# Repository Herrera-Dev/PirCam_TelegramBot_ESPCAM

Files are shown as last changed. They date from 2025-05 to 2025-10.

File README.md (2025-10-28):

# ESP32-CAM con TelegramBot

Consiste en un sistema de monitores de seguridad basado en un **ESP32-CAM**, que interactúa con un bot de **Telegram**. El dispositivo captura fotos usando la cámara integrada y las envía a los usuarios registrados cuando detecta movimiento mediante un sensor PIR. Además, tiene múltiples funcionalidades controlables a través de Telegram, como **activar o desactivar el modo de vigilancia**, **tomar fotos bajo demanda**, **transmitir video en la red local** o **controlar el modo de ahorro de energía.**

> ⚠️ Al encenderse, la ESP32-CAM intenta cargar las configuraciones almacenadas. Si no encuentra el **token del bot**, las **credenciales Wi-Fi** o al menos **un usuario**, entra en modo configuración usando **WiFiManager** para obtener estos datos para obtenerlos.

<p align="center">
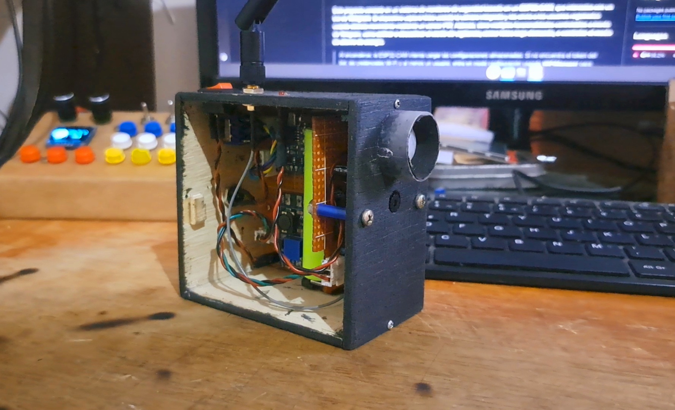
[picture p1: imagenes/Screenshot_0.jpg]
  
</p>

## 🛠️ Configuración del Entorno
### Software
- **IDE:** Arduino `v1.8.x` o `v2.3.x`
- **Framework:** Arduino ESP32 `v3.0.7`
- **Board:** `AI Thinker ESP32-CAM`
- **Partition:** `Regular 4MB with spiffs(1.2MB APP/1.5MB SPIFFS).`</b>    
  En caso de usar la función de **OTA**: `Minimal SPIFFS(1.9 APP with OTA/ 190KB SPIFFS).`

### Librerías

- **WiFiManager** `v2.0.17`: Para gestionar la conexión Wi-Fi.
- **UniversalTelegramBot** `v1.3.0`: Para la integración con el bot de Telegram.
- **ArduinoJson** `v7.4.1`: Para el manejo de JSON en la comunicación con el bot de Telegram.
- **TelnetStream** `v1.3.0`: Usar solo si no dispone de una comunicación serial.

## 🔧 Hardware

- 1x Board ESP32-CAM y antena externa (opcional).
- 1x Sensor de movimiento PIR HC-SR501.
- 1x Step-Up MT3608 DC-DC
- 1x Modulo de carga TP4056.
- 1x Portabateria 18650.
- 1x Bateria 18650.
- 1x Interruptor 6P DPDT.
- 1x Diodo led.
- Resistencias 100 kohm, 10 kohm y 100 ohm.

## 🔌 Diagrama

<p align="center">
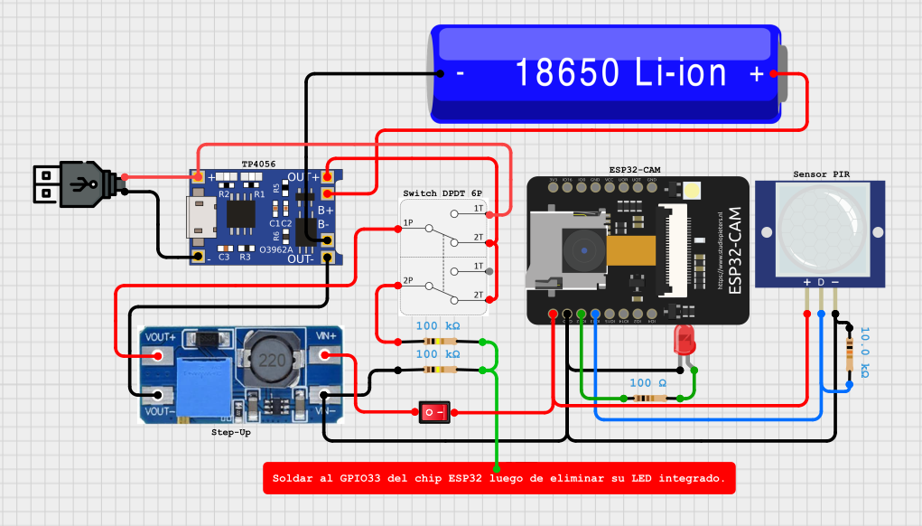
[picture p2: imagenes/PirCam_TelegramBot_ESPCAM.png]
Circuito
  
</p>

---

> ⚠️ Primero verificar que funcione bien la **PSRAM** de la la placa **ESP32-CAM** usando el modelo de placa: **AI Thinker ESP32-CAM** al parecer algunas unidades tienen ese defecto desde fabrica.

```c
#include <Arduino.h>
void setup() {
  Serial.begin(115200);
  delay(1000);

  if (psramFound()) {
    Serial.println("PSRAM está habilitada y funcionando.");
  } else {
    Serial.println("PSRAM no está habilitada o disponible.");
  }
}

void loop() {
}
```

> Si ocurren fallas como `Error al iniciar la camara`, `Error al capturar la foto` o `reinicios por culpa del WDT` recomendacion desactivar la funcion del **Watchdogs**.

## 🖼️ Capturas

<p align="center">
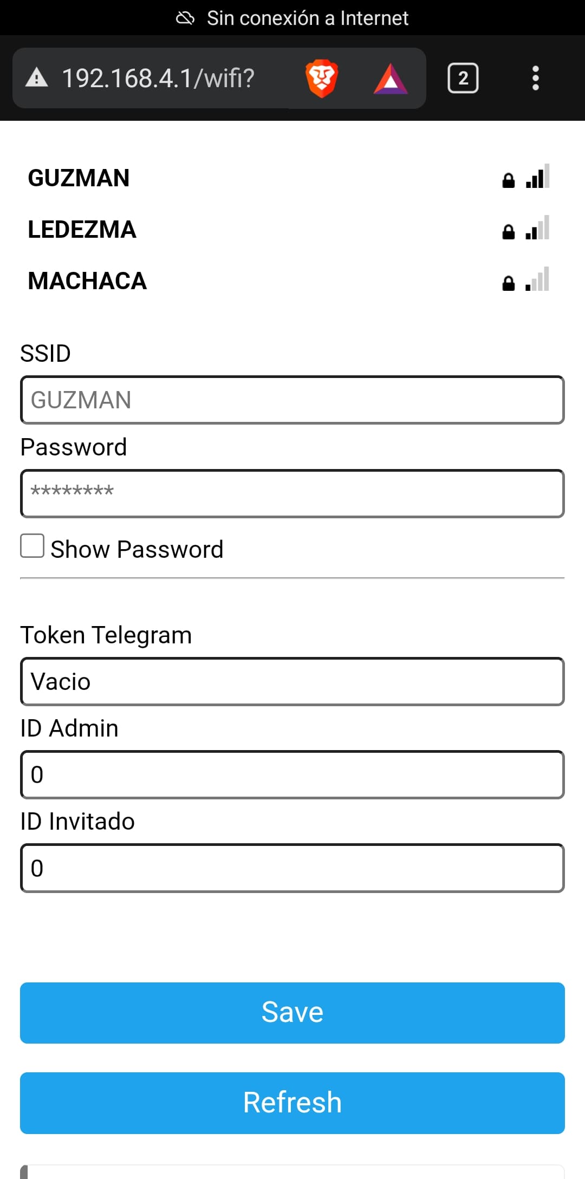
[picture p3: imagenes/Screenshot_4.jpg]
  
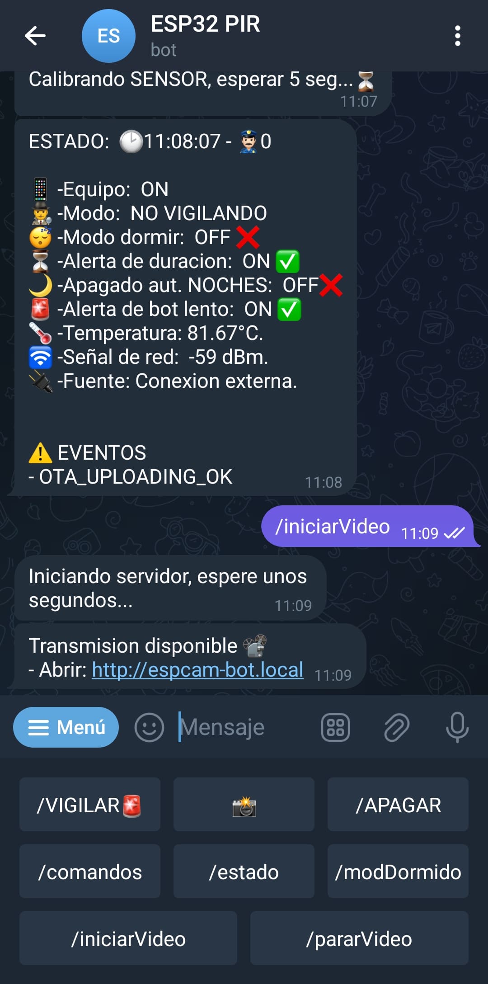
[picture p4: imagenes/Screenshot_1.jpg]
  
</p>

<p align="center">
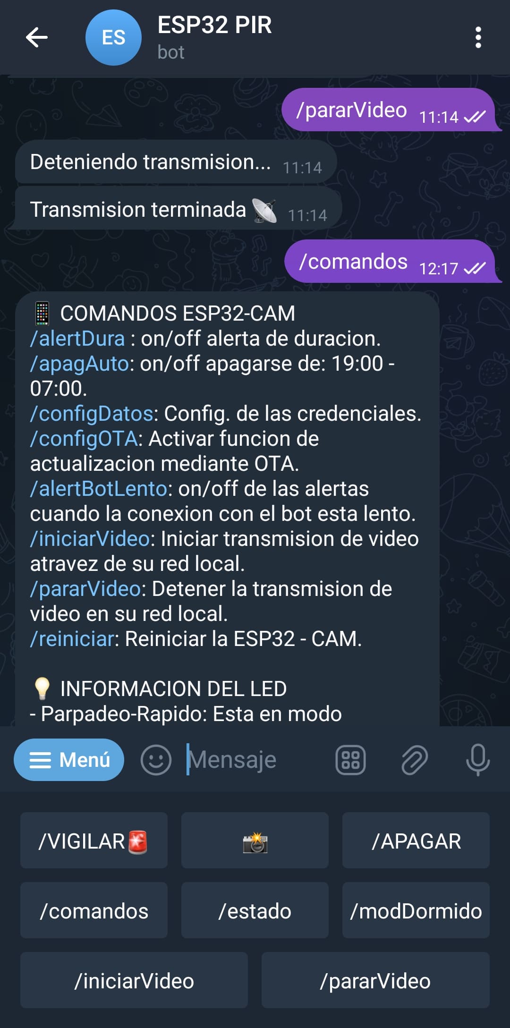
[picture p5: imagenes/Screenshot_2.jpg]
  
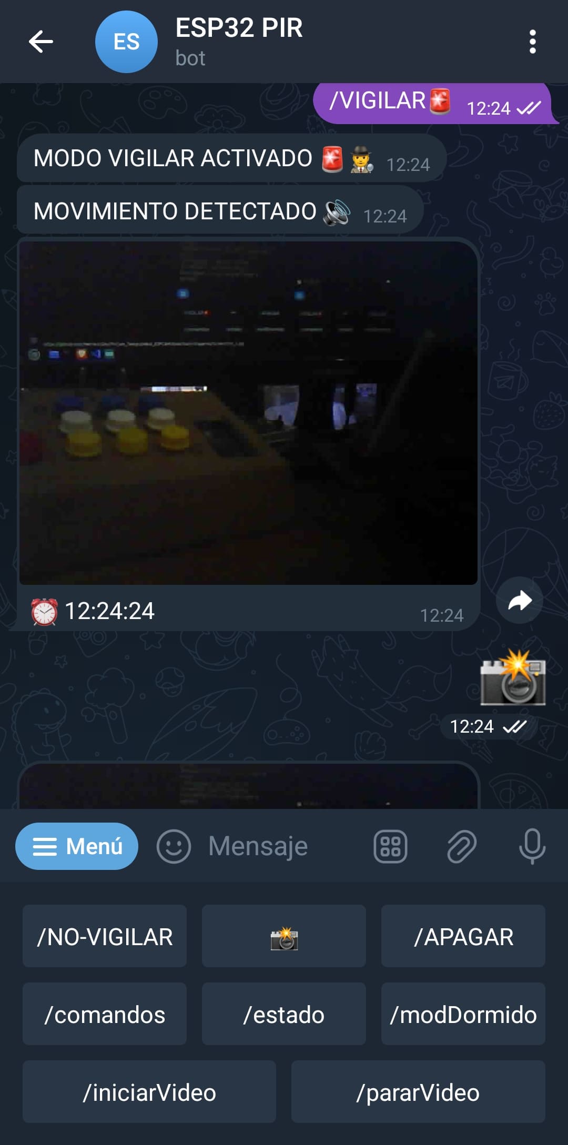
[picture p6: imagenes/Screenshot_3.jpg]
  
</p>

## 🌐 Características del Bot de Telegram

| **Comando** | **Descripción** |
|---|---|
| `/estado` | Muestra el estado del sistema: <ul><li>Hora actual y número de usuarios en vigilancia</li><li>Estado del dispositivo (ON/OFF)</li><li>Modo vigilancia (ON/OFF)</li><li>Modo ahorro de energía (ON/OFF)</li><li>Alerta de duración del movimiento (ON/OFF)</li><li>Apagado automático (ON/OFF)</li><li>Temperatura interna *(SENSOR INTERNO NO CONFIABLE)*</li><li>Intensidad de la señal WiFi</li><li>Tipo de alimentación (externa o batería)</li></ul> |
| `/VIGILAR` / `/NO-VIGILAR` | Activa o desactiva el modo vigilancia. Envía foto al detectar movimiento. |
| `/foto` | Solicita una foto en cualquier momento. |
| `/APAGAR` / `/ENCENDER` | Apaga o enciende el dispositivo. Usa *deep sleep* al apagarse. |
| `/modDormido` / `/modDespierto` | Activa o desactiva el modo ahorro de energía (deep sleep con PIR). |
| `/iniciarVideo` / `/pararVideo` | Iniciar o detener la transmisión de video a través de su red local: [http://espcam-bot.local](http://espcam-bot.local) --> [VER IMAGEN](imagenes/Screenshot_5.jpg)|
| `/comandos` | Muestra comandos adicionales y alerta LED:<ul><li>`/alertDura`: ON/OFF – LED se mantiene encendido con movimiento.</li><li>`/apagAuto`: ON/OFF – Apagado automático nocturno.</li><li>`/configOTA`: Activar OTA (solo admin).</li><li>`/configDatos`: Reinicia para reconfigurar con WiFiManager (solo admin).</li><li>`/reiniciar`: Reinicia la ESP32-CAM.</li></ul> |

  ```c
  💡 INFORMACION DEL LED
  - Parpadeo_Rapido: Esta en modo configuración o error de acceso a la memoria.
  - Parpadeo_Normal: Calibrando sensor luego de iniciar.
  - Un Parpadeo: Captura una foto.
  - Encendido: Cuando se detecta movimiento (solo si esta activado la opcion `/alertDura`).
  ```

- **Alerta de batería**: Notificar si la batería baja por debajo del 15% cuando se esta usando la batería como fuente de alimentacion.
- **Lentitud con el bot**: Cuando esta en modo-vigilar notificar si el bot tarda en verificar la existencia de nuevos mensajes y eso genera un retraso en cada interacción.
- **Sobrecalentamiento**: Notificar cuando el sensor interno de temperatura alcance un umbral definido, (**CABE ACLARAR QUE EL SENSOR INTERNO DE ESTA ESP32 NO ES CONFIABLE**) recomendación usar usar un sensor externo.
> ⚠️ Las mensajes de posible fallo se muestra en los **mensajes de bienvenida** o en el **portal de WifiManager**.

### Calidad de imagen y video
La **calidad de las imagenes** se debe cambiar desde `void configCamara()` **mayor calidad** y **tamaño de imagen** significa mayor consumo electrico y menor rendimiento de la ESP32.

```c
config.frame_size = FRAMESIZE_VGA; // FRAMESIZE_ + QVGA|CIF|VGA|SVGA|XGA|SXGA|UXGA 
config.jpeg_quality = 30;          // 0-63 un número más bajo significa mayor calidad de imagen.
```

### Funciones Dev
En caso de realizar modificaciones.

- **Actualización OTA (Over-the-Air):** **(Aunque esta funcion ya biene integrada en WifiManager)**. El proyecto incluye la funcionalidad de actualización OTA, lo que permite cargar nuevo firmware de forma remota a través de la red Wi-Fi. Esto resulta especialmente útil en la ESP32-CAM, ya que este modelo no cuenta con un puerto USB integrado. Esta función simplifica el mantenimiento sin necesidad de acceso físico al dispositivo.

- **Depuración Remota con TelnetStream:** Incorpora la librería TelnetStream, que permite realizar la depuración del dispositivo de forma remota mediante una conexión Telnet a traves de la red Wi-Fi. Esto resulta especialmente útil para analizar el comportamiento del dispositivo en tiempo real sin necesidad de una conexión física al puerto serial, ideal si se requiere realizar mejoras.

## 📄Flujo de Operaciones

1. **Encendido y Carga de Configuración**: Al encenderse, el dispositivo carga la configuración desde la memoria flash. Si los datos no están disponibles (`token del bot`, `credenciales Wi-Fi`, o `usuario registrado`), entra en **modo configuración** **`(AP mode)`** usando **WiFiManager** para recopilar la información.

2. **Interacción con el Bot**: Una vez configurado, el bot de Telegram interactúa con el dispositivo a través de los comandos definidos. Cada comando tiene una acción específica, como cambiar el modo de vigilancia, tomar fotos o modificar configuraciones de ahorro de energía.
3. **Eventos**: Si hubo un reinicio inesperado informar las causa o de algun otro problema referido a los datos de inicio.
4. **Notificaciones**: El sistema envía notificaciones a los usuarios registrados en caso de que la batería baje por debajo del 15%, sobre calentamiento y cuando el sensor PIR detecta movimiento.

## Script `Proxy_Video_ESP32.py`
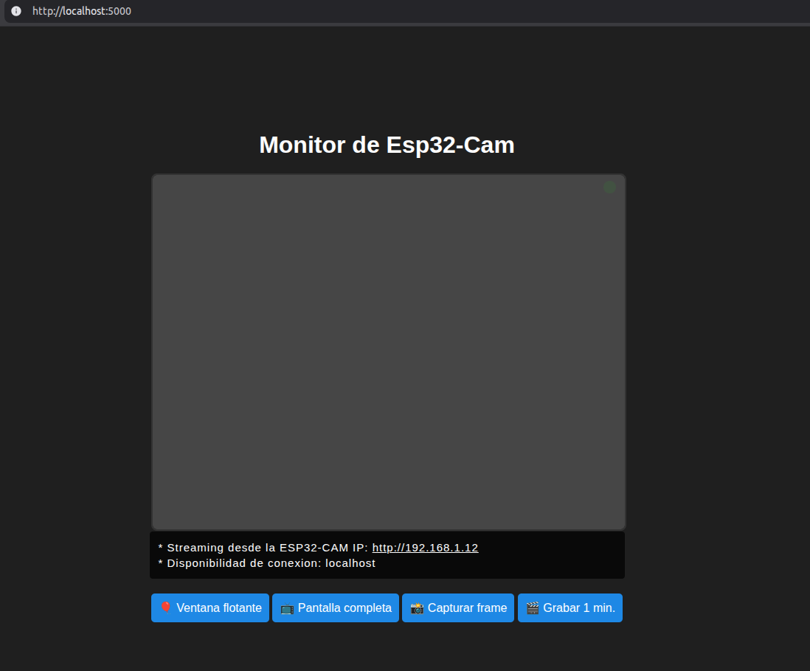
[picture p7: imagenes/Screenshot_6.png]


Este script es un servidor proxy en Flask para retransmitir el video de la ESP32-CAM a través de una interfaz web personalizado lo cual permite ver el video en **Picture-in-Picture (PiP)**, **Pantalla completa**, **Capturar imagen** y **Grabar video**. Si no requiere estas funciones simplemente ingrese a: [http://espcam-bot.local](http://espcam-bot.local) o a la IP de la esp32-cam. 
1. **Instalar Python**:
   Asegúrate de tener **Python 3.10** o superior instalado en tu sistema. Puedes descargarlo desde [python.org](https://www.python.org/).

2. **Instalar las dependencias**:
   Ejecuta el siguiente comando para instalar las librerías necesarias, flask `v3.1.x` y ffmpeg `v4.4.x` para el video:
   ```bash
   sudo apt install ffmpeg
   pip install flask pillow requests imagehash plyer

   ```

3. **Ejecutar el script**:
   Inicia el servidor ejecutando el script:
   ```bash
   python3 Proxy_Video_ESP32.py
   ```
4. **Acceder al servidor**:
   - Para acceder, abre [http://localhost:5000](http://localhost:5000) en tu navegador.

## Play Store app: `TinyCam Monitor`
Funciona excelente con [TinyCam Monitor](https://play.google.com/store/apps/details?id=com.alexvas.dvr) si tambien requiere esas funciones en el dispositivo mobile: **Picture-in-Picture (PiP)**, **Pantalla completa**, **Capturar imagen** y **Grabar video** y ademas contiene funciones de detención de **movimiento**, **personas**, **mascotas** y **vehiculos**.
Contiene notificaciones de eventos atravez de **correo** y **telegram**.

### Configuracion
- **Fabricante de camara**: `(Generic)`
- **Modelo de camara**: `Generic URL`
- **Peticion JPEG/MJPEG/RTSP**: `http://espcam-bot.local/video`
- **Protocolo**: `Snapshot (JPEG)`

## 💡 Consideraciones

- Tener una conexión Wi-Fi estable para interactuar con el bot de Telegram.
- El modo **deep sleep** es útil cuando se utiliza la batería para prolongar la duracion de la batería pero desde la detencion del movimiento hast que sea enviado hay un retraso mas largo de milisegundos que al no usar el modo deep sleep.

## ⚡ Alternar entre fuente externa y bateria

Circuito para conmutar la alimentacion entre la bateria y una fuente externa 5V. [VER IMAGEN](imagenes/Conmutacion.jpg)

> ⚠️ Si el dispositivo está conectado a una fuente de alimentación externa, se recomienda no utilizar la batería simultáneamente. El modulo TP4056 no esta diseñado para cargar la bateria y alimentar el dispositivo al mismo tiempo, lo que podría provocar sobrecargas y ser peligroso. Usa la batería únicamente cuando no dispongas de una fuente externa. 

- [Añadir cargador de batería a ESP8266 y ESP32](https://emariete.com/cargador-bateria-esp8266-esp32-bien-hecho/)

## 🔋 Nivel de la bateria
### ⚠️ Uso de GPIO33 para medir el nivel de batería en ESP32-CAM

En la placa ESP32-CAM, solo los pines ADC2 están disponibles externamente. Sin embargo, los pines ADC2 son utilizados internamente por el controlador Wi-Fi o por la microSD, por lo que **no pueden ser usados para lecturas analógicas mientras el Wi-Fi está habilitado**.

Por defecto, el pin **GPIO33** que es ADC1 está conectado al LED integrado de la placa. Para utilizar este pin como entrada analógica para medir el nivel de la batería, **se debe desoldar el LED integrado** que está conectado a GPIO33. De esta forma, podrás conectar el divisor resistivo para la medición de voltaje de la batería a este pin.
<p align="center">
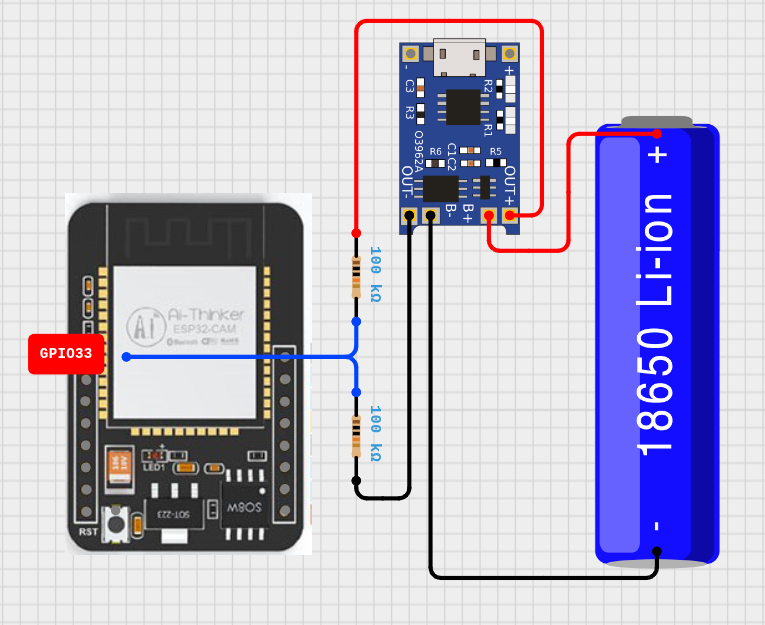
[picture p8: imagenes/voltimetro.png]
  
</p>

- [Battery Status Monitoring System using ESP8266 & Arduino IoT Cloud](https://iotprojectsideas.com/battery-status-monitoring-system-using-esp8266-arduino-iot-cloud/)
- [ESP8266 Monitor its Own Battery Level using IoT](https://iotprojectsideas.com/esp8266-monitor-its-own-battery-level-using-iot/)
- [IoT Based Battery Status Monitoring System using ESP8266](https://how2electronics.com/iot-based-battery-status-monitoring-system-using-esp8266/)

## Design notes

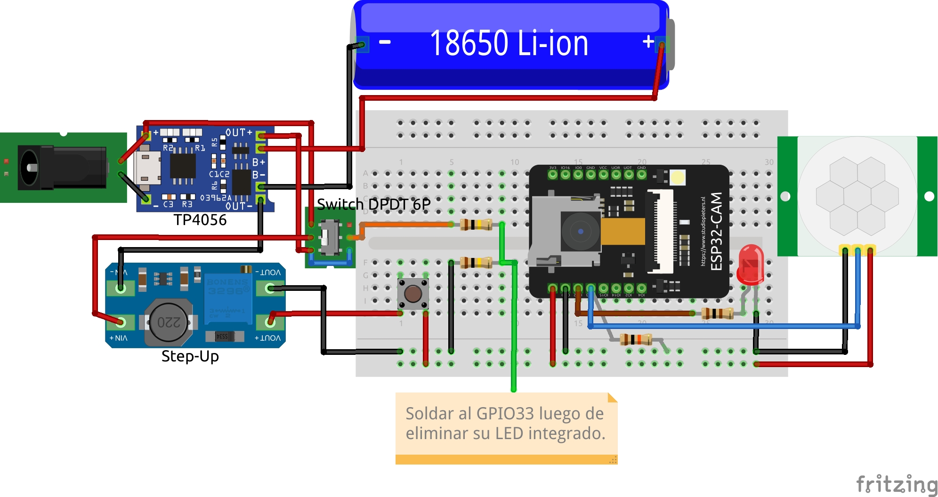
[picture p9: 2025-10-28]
imagenes/PirCam_TelegramBot_ESPCAM_bb.jpg

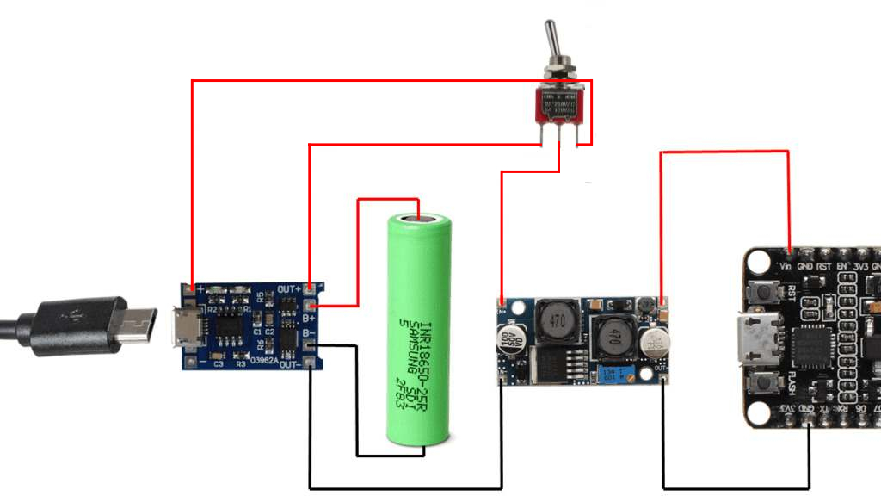
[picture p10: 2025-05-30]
imagenes/Conmutacion.jpg

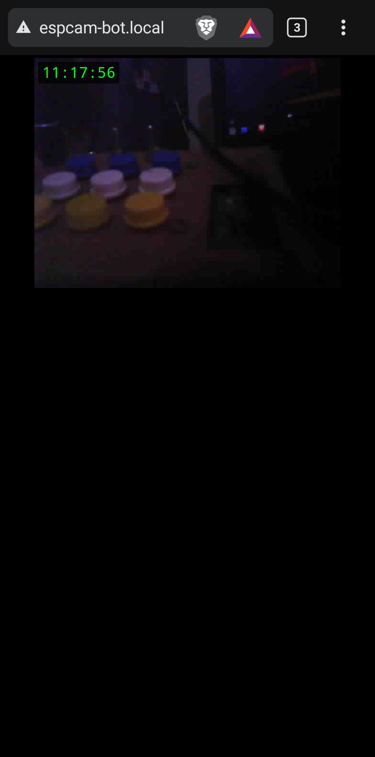
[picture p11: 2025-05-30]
imagenes/Screenshot_5.jpg

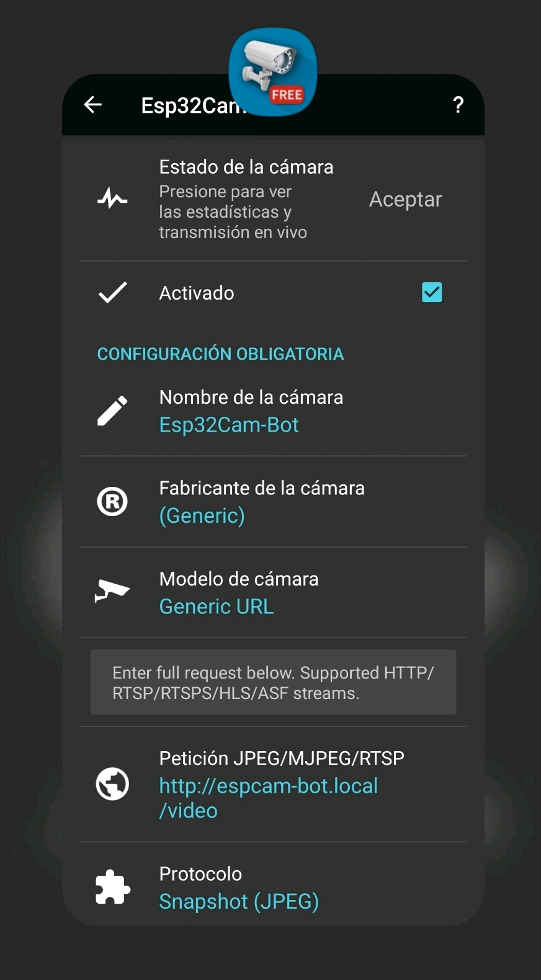
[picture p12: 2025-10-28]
imagenes/TinyCamMonitor.jpg

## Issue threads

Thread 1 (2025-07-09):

Felicitaciones y pregunta ...

zilhos, 2025-07-09:
Hola, gracias por compartir su trabajo,me parecio muy bueno . Felicitaciones por los logros !
Tuve que eliminar con mi poco conocimiento de programacion la dependencia de wifimanager y optar por un web para la configuracion de credenciales.
Pregunta ... : sera posible integrar la deteccion de movimiento mediante el sensor de la camara y no depender de un pir? Entiendo que no seria mas un proyecto de bajo consumo electrico pero tal vez su conocimiento en programacion pueda lograr esto facilmente .
Nuevamente gracias por compartir, apoyo su trabajo que es muy bueno .
Saludos

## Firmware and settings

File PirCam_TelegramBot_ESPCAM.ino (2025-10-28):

#define WDT 0          // Funcionamiento del WatchDog.
#define TIEMP_MOV_F 1  // El tiempo de movimiento manejamos de forma manual o por el pontenciometro del PIR.
#define RESET_NVC 0    // Limpiar la memoria NVC.
#define DEPURACION_T 0 // Depurar por telnet.
#define OTA 1          // Actualizacion por OTA

#if RESET_NVC
#include <nvs_flash.h>
#endif
#if WDT
#include <esp_task_wdt.h>
#endif
#if DEPURACION_T
#include <TelnetStream.h>
#endif
#if OTA
#include <ArduinoOTA.h>
#include "config_OTA.hpp"
#endif

#include "esp_system.h"
#include <WiFi.h>
#include "esp_timer.h"
#include "fb_gfx.h"
#include "esp_http_server.h"
#include "esp_sleep.h"
#include "soc/soc.h"
#include "soc/rtc_cntl_reg.h"
#include "esp_camera.h"
#include <Preferences.h>
#include <WiFiClientSecure.h>
#include <UniversalTelegramBot.h>
#include <ESPmDNS.h>
#include <WiFiManager.h>
#include <Ticker.h>
#include "pines_cam.h"

#ifdef __cplusplus
extern "C"
{
#endif
  uint8_t temprature_sens_read();
#ifdef __cplusplus
}
#endif

#define PART_BOUNDARY "123456789000000000000987654321"
static const char *_STREAM_CONTENT_TYPE = "multipart/x-mixed-replace;boundary=" PART_BOUNDARY;
static const char *_STREAM_BOUNDARY = "\r\n--" PART_BOUNDARY "\r\n";
static const char *_STREAM_PART = "Content-Type: image/jpeg\r\nX-Timestamp: %s\r\nContent-Length: %u\r\n\r\n";

Preferences memoria;
WiFiClientSecure clientTCP;
UniversalTelegramBot bot("", clientTCP);
#define pinLed 12
#define pinPir 13
#define analogBat 33

const char *npt = "pool.ntp.org";
const char *myDomain = "api.telegram.org";
const char *hostname = "ESPCAM-BOT";
const char *hostpass = "12345678";

const int BOT_MTBS = 2400;          // mSeg.
const int RETRASO_FOT = 600;        // mSeg.
const int ESPERAR_MOV_FIJO = 15000; // mSeg. Tiempo de espera antes de detectar nuevo mov.
const float CALIBRACION_BAT = 0.20; // mas voltaje
byte FPS_VIDEO = 7;                 // Emular limitacion de FPS (~10fps = 100ms  experiment)

const int tPanico = 60;  // Reinciar en caso de congelarse mas de 60 seg. via Watchdog.
const int hApagAut = 19; // PM, Apagdo automatico 19:00 horas.
const int hEncAut = 7;   // AM, Encendido automatico 07:00 horas.

RTC_DATA_ATTR int ultimoMsjBot = 0;
struct tm timeinfo;
struct users
{
  char id[12];
  char nomb[10];
  bool estado;
};

char token[50] = "vacio";
users usuarios[2] = {{"0", "Adm", false}, {"0", "Inv", false}};
bool solicFot[2] = {false, false};
bool alertMov = false;
bool usrAct;

char text[20];
bool modConfig = false;
bool enviarFoto = false;
bool apagado = false;
bool movimiento = false;
bool modAhorro = false;
bool alertTiemp = true;
bool apagadoAuto = false;
bool apagadoMan = false;
bool funcOTA = false;
bool usrActivo = false;
bool alertBotLent = true;
bool invitadActive = false;

byte desc = 0;
String errorRes = "";
unsigned long tAntMensaj;
unsigned long tAntBat;

typedef struct
{
  httpd_req_t *req;
  size_t len;
} jpg_chunking_t;

bool client_active = false;
bool stream_active = false;
httpd_handle_t stream_httpd = NULL; // Streaming
httpd_config_t config;

void getDatos()
{
  memoria.begin("memory", true);
  delay(20);
  modAhorro = memoria.getBool("modDormir", false);
  alertTiemp = memoria.getBool("alertTiemp", false);
  apagado = memoria.getBool("estApag", false);
  modConfig = memoria.getBool("config", false);
  apagadoAuto = memoria.getBool("apagAut", false);
  apagadoMan = memoria.getBool("apagadMan", false);
  funcOTA = memoria.getBool("funcOta", false);
  errorRes = memoria.getString("error", "");
  invitadActive = memoria.getBool("invActive", false);
  ultimoMsjBot = memoria.getInt("ultMsj", 0);

  memoria.getBytes("tkn", token, sizeof(token));
  size_t peopleSize = memoria.getBytes("users", usuarios, sizeof(usuarios));
  delay(10);
  memoria.end();

  if (peopleSize == 0)
  {
    Serial.println(F("No se pudieron cargar los datos."));
    errorRes += "E: Cargar datos.";
    for (uint8_t i = 0; i < 254; i++)
    {
      delay(100);
      alertaLED();
    }
    digitalWrite(pinLed, LOW);
  }
  usrActivo = usuarios[0].estado || usuarios[1].estado;
}
void setString(const char *err)
{
  memoria.begin("memory", false);
  memoria.putString("error", err);
  memoria.end();
}
void setBool(const char *d, bool v)
{
  memoria.begin("memory", false);
  memoria.putBool(d, v);
  memoria.end();
}
void setInt(const char *d, int v)
{
  memoria.begin("memory", false);
  memoria.putInt(d, v);
  memoria.end();
}

void configCamara()
{
  camera_config_t config;
  config.ledc_channel = LEDC_CHANNEL_0;
  config.ledc_timer = LEDC_TIMER_0;
  config.pin_d0 = Y2_GPIO_NUM;
  config.pin_d1 = Y3_GPIO_NUM;
  config.pin_d2 = Y4_GPIO_NUM;
  config.pin_d3 = Y5_GPIO_NUM;
  config.pin_d4 = Y6_GPIO_NUM;
  config.pin_d5 = Y7_GPIO_NUM;
  config.pin_d6 = Y8_GPIO_NUM;
  config.pin_d7 = Y9_GPIO_NUM;
  config.pin_xclk = XCLK_GPIO_NUM;
  config.pin_pclk = PCLK_GPIO_NUM;
  config.pin_vsync = VSYNC_GPIO_NUM;
  config.pin_href = HREF_GPIO_NUM;
  config.pin_sscb_sda = SIOD_GPIO_NUM;
  config.pin_sscb_scl = SIOC_GPIO_NUM;
  config.pin_pwdn = PWDN_GPIO_NUM;
  config.pin_reset = RESET_GPIO_NUM;
  config.xclk_freq_hz = 15000000; // default: 20000000 20MHz
  config.pixel_format = PIXFORMAT_JPEG;
  config.grab_mode = CAMERA_GRAB_LATEST;

  if (psramFound())
  {
    // Serial.(println(F("Calidad Alta"));
    config.frame_size = FRAMESIZE_VGA; // FRAMESIZE_ + QVGA|CIF|VGA|SVGA|XGA|SXGA|UXGA
    config.jpeg_quality = 30;          // 10  0-63 un número más bajo significa mayor calidad
    config.fb_count = 2;
  }
  else
  {
    // Serial.println(F("Calidad Baja"));
    config.frame_size = FRAMESIZE_QVGA;
    config.jpeg_quality = 25; // 12  0-63 un número más bajo significa mayor calidad
    config.fb_count = 2;
  }
  delay(1500);

  // inicio de cámara
  esp_err_t err = esp_camera_init(&config);
  delay(500);

  if (err != ESP_OK)
  {
    err = esp_camera_init(&config);
  }

  if (err != ESP_OK)
  {
    Serial.printf("ERROR AL INICIAR LA CAMARA, ERROR: 0x%x", err);
    bot.sendMessage(usuarios[0].id, "⏳Error al iniciar la camara\nReiniciando... ⬇", "");
    delay(6000);
    ESP.restart();
  }
}

void confWifiManager()
{
  WiFi.mode(WIFI_AP);
  WiFiManager wm;

  WiFiManagerParameter nuevoToken("Token", "Token Telegram", token, sizeof(token));
  WiFiManagerParameter nuevoAdm("Admin", "ID Admin", usuarios[0].id, sizeof(usuarios[0].id));
  WiFiManagerParameter nuevoInv("Invitado", "ID Invitado", usuarios[1].id, sizeof(usuarios[1].id));
  const String n = "<p style='color: red; text-align: center;'>" + errorRes + "</p>";
  WiFiManagerParameter customMessage(n.c_str());
  wm.addParameter(&nuevoToken);
  wm.addParameter(&nuevoAdm);
  wm.addParameter(&nuevoInv);
  wm.addParameter(&customMessage);

  // wm.setShowDnsFields(true);
  // wm.setShowInfoErase(false);
  wm.setBreakAfterConfig(true); // Guardar a un que las credenciales Telegram a un que las credenciales wifi sean incorrectas.
  wm.setConfigPortalTimeout(180);
  wm.setConnectTimeout(10);
  wm.startConfigPortal(hostname, hostpass);

  Serial.println(F("CONFIGURACION TERMINADO"));
  strncpy(token, nuevoToken.getValue(), sizeof(token));
  strncpy(usuarios[0].id, nuevoAdm.getValue(), sizeof(usuarios[0].id));
  strncpy(usuarios[1].id, nuevoInv.getValue(), sizeof(usuarios[1].id));

  if (strlen(token) < 2)
  {
    strncpy(token, "vacio", sizeof(token));
  }

  for (int i = 0; i < 2; i++)
  {
    if (strlen(usuarios[i].id) < 10)
    {
      strncpy(usuarios[i].id, "0", sizeof(usuarios[i].id));
      usuarios[i].estado = false;
    }
  }

  memoria.begin("memory", false);
  memoria.putBytes("tkn", token, sizeof(token));
  memoria.putBytes("users", usuarios, sizeof(usuarios));
  memoria.end();
  delay(1000);
  ESP.restart();
}

void configInicio()
{
  if (modConfig)
  {
    // Serial.println(F("MODO CONFIGURACION"));
    Ticker ledParp;
    setBool("config", false);
    ledParp.attach(0.1, alertaLED);
    confWifiManager();
    ledParp.detach();
    delay(1000);
    ESP.restart();
  }

  WiFi.mode(WIFI_STA);
  WiFiManager wm;
  wm.setHostname(hostname);
  wm.setConnectTimeout(15);
  wm.setConfigPortalTimeout(3);
  // wm.resetSettings();

  if (wm.autoConnect())
  {
    bot.updateToken(token);
    clientTCP.setCACert(TELEGRAM_CERTIFICATE_ROOT);
    delay(2000);

    byte tiemp = 0;
    while (!clientTCP.connect(myDomain, 443) && tiemp < 70)
    {
      if (tiemp == 69)
      {
        if (errorRes.length() < 60)
        {
          errorRes += " E: Conexion a Internet, API.\n";
          setString(errorRes.c_str());
        }
        setBool("config", true);
        delay(1000);
        ESP.restart();
      }
      tiemp++;
      delay(200);
    }
    clientTCP.stop();

    // Iniciar mDNS
    if (MDNS.begin(hostname))
    {
      Serial.print("mDNS iniciado");
      Serial.print(": http://");
      Serial.print(hostname);
      Serial.println(F(".local"));
    }
    else
    {
      Serial.println(F("Error al iniciar mDNS"));
    }
  }
  else
  {
    Serial.println(F("NO HAY CONEXION WIFI"));
    if (errorRes.length() < 60)
    {
      errorRes += " E: Conexion al WiFi.\n";
      setString(errorRes.c_str());
    }
    setBool("config", true);
    delay(1000);
    ESP.restart();
  }

  if (String(usuarios[0].id) == "0" && String(usuarios[1].id) == "0")
  {
    Serial.println(F("NO HAY USUARIOS REGISTRADOS"));
    if (errorRes.length() < 60)
    {
      errorRes += " E: No hay usuarios.\n";
      setString(errorRes.c_str());
    }
    setBool("config", true);
    delay(1000);
    ESP.restart();
  }

#if OTA
  if (funcOTA)
  {
    // Serial.println(F(FUNCION OTA DISPONIBLE));
    InitOTA();
    setBool("funcOta", false);
    bot.sendMessage(usuarios[0].id, "Actualizacion por OTA habilitado. ⚙\n- IP: " + WiFi.localIP().toString() + "\n- Pass: " + String(hostpass), "");
    while (true)
    {
      ArduinoOTA.handle();
      delay(10);
    }
  }
#endif
  delay(100);
}

String eventosError()
{
  String errorCras = "";
  esp_reset_reason_t resetReason = esp_reset_reason();
  switch (resetReason)
  {
  case ESP_RST_UNKNOWN:
    errorCras = "R: causa desconocida.";
    break;
  case ESP_RST_EXT:
    errorCras = "R: Pin externo.";
    break;
  case ESP_RST_PANIC:
    errorCras = "R: Panico (crash)";
    break;
  case ESP_RST_INT_WDT:
    errorCras = "R: Watchdog (WDT)";
    break;
  case ESP_RST_TASK_WDT:
    errorCras = "R: Tarea del watchdog";
    break;
  case ESP_RST_WDT:
    errorCras = "R: Otro tipo de WDT reinicio";
    break;
  case ESP_RST_BROWNOUT:
    errorCras = "R: Bajo voltaje (brownout)";
    break;
  case ESP_RST_SDIO:
    errorCras = "R: Error en SDIO";
    break;
    /*case ESP_RST_SW:
    errorCras = "Reinicio por ESP.restart()";
    break;
    case ESP_RST_POWERON:
    errorCras = "Reinicio por encendido.";
    break;
    case ESP_RST_DEEPSLEEP:
    errorCras = "R: salida de Deep Sleep.";
    break;*/
  }

  if (!errorCras.isEmpty() || !errorRes.isEmpty())
  {
    String txt = "\n\n⚠ EVENTOS ";
    if (!errorRes.isEmpty())
    {
      txt += "\n- " + errorRes;
    }
    if (!errorCras.isEmpty())
    {
      txt += "\n- " + errorCras;
    }
    setString("");
    errorCras = txt;
  }
  return errorCras;
}

void alertaLED()
{
  digitalWrite(pinLed, !digitalRead(pinLed)); // Cambia el estado del LED
}

void mod_dormir()
{
#if WDT
  // esp_task_wdt_delete(NULL);
  esp_task_wdt_deinit();
#endif
  esp_sleep_enable_ext0_wakeup(GPIO_NUM_13, 1); // Despertar con señal alta
  delay(2000);
  esp_deep_sleep_start();
}

void mod_apagado(int n)
{
#if WDT
  // esp_task_wdt_delete(NULL);
  esp_task_wdt_deinit();
#endif
  unsigned long tmp = n * 1000000; // n = segundos
  esp_sleep_enable_timer_wakeup(tmp);
  delay(1000);
  esp_deep_sleep_start();
}

void apaAutomat()
{
  if (apagadoAuto)
  {
    if (hActual().substring(0, 2).toInt() == hApagAut)
    {
      ultimoMsjBot = bot.messages[0].message_id;
      setBool("estApag", apagado = true);
      for (uint8_t i = 0; i < 2; i++)
      {
        if (strlen(usuarios[i].id) > 9 && invAct(i))
        {
          bot.sendMessageWithReplyKeyboard(usuarios[i].id, "Equipo APAGADO AUT.📵", "", estadoMenu(i), true);
        }
      }
      stream_active = false;
      stopCameraServer();
      mod_apagado(3700);
    }
  }
}

#if WDT
void iniciar_WDT()
{
  esp_task_wdt_deinit();
  esp_task_wdt_config_t wdt_config = {.timeout_ms = tPanico * 1000, .trigger_panic = true};
  esp_task_wdt_init(&wdt_config);
  esp_task_wdt_add(NULL);
}
#endif

// -------------------------------
static esp_err_t index_handler(httpd_req_t *req)
{
  const char *html = R"rawliteral(
<!DOCTYPE html>
<html>
<head>
  <meta charset="UTF-8">
  <title>ESPCAM-BOT</title>
  <style>
    body { background: black; color: lime; font-family: monospace; text-align: center; }
    #video-container { position: relative; display: inline-block; }
    #hora { position: absolute; top: 10px; left: 10px; background: rgba(0, 0, 0, 0.7); padding: 5px 10px; font-size: 40px; border-radius: 4px; }
  </style>
</head>
<body>
  <div id="video-container">
    <div id="hora">Cargando hora...</div>
    <canvas id="video" width="800px" height="600px"></canvas>
    <script>
      const canvas = document.getElementById('video');
      const ctx = canvas.getContext('2d');
      const horaElem = document.getElementById('hora');

      let streamTimeout;
      let controller = new AbortController();

      function iniciarStream() {
        controller = new AbortController();

        streamTimeout = setTimeout(() => {
          console.warn('Stream congelado. Recargando página...');
          location.reload(); // o window.location.href = "/";
        }, 4000);

        fetch('/video', { signal: controller.signal }).then(res => {
          const reader = res.body.getReader();
          let buffer = new Uint8Array();

          function concatBuffer(a, b) {
            let tmp = new Uint8Array(a.length + b.length);
            tmp.set(a, 0);
            tmp.set(b, a.length);
            return tmp;
          }

          function findJPEG(buf) {
            for (let i = 0; i < buf.length - 1; i++) {
              if (buf[i] === 0xFF && buf[i + 1] === 0xD8) {
                for (let j = i + 2; j < buf.length - 1; j++) {
                  if (buf[j] === 0xFF && buf[j + 1] === 0xD9) {
                    return buf.slice(i, j + 2);
                  }
                }
              }
            }
            return null;
          }

          function leer() {
            reader.read().then(({ value, done }) => {
              if (done) return;
              clearTimeout(streamTimeout); // llegó algo, reiniciar timeout
              streamTimeout = setTimeout(() => {
                console.warn('Stream colgado. Recargando...');
                location.reload();
              }, 4000);

              buffer = concatBuffer(buffer, value);

              const textChunk = new TextDecoder().decode(value);
              const match = textChunk.match(/X-Timestamp:\s(.+)\r\n/);
              if (match) {
                horaElem.textContent = match[1];
              }

              const jpeg = findJPEG(buffer);
              if (jpeg) {
                const blob = new Blob([jpeg], { type: 'image/jpeg' });
                const url = URL.createObjectURL(blob);
                const img = new Image();
                img.onload = () => {
                  ctx.drawImage(img, 0, 0, canvas.width, canvas.height);
                  URL.revokeObjectURL(url);
                };
                img.src = url;
                buffer = new Uint8Array(); // limpiar buffer
              }

              leer();
            }).catch(err => {
              console.error('Error al leer stream:', err);
              location.reload();
            });
          }

          leer();
        }).catch(err => {
          console.error('Error de conexión:', err);
          location.reload();
        });
      }

      iniciarStream();
    </script>

  </div>
</body>
</html>
)rawliteral";

  httpd_resp_set_type(req, "text/html");
  return httpd_resp_send(req, html, HTTPD_RESP_USE_STRLEN);
}

static esp_err_t stream_handler(httpd_req_t *req)
{
  client_active = true;

  camera_fb_t *fb = NULL;
  esp_err_t res = ESP_OK;
  size_t _jpg_buf_len = 0;
  uint8_t *_jpg_buf = NULL;
  char part_buf[128];

  httpd_resp_set_hdr(req, "Access-Control-Allow-Origin", "*");
  httpd_resp_set_hdr(req, "Cache-Control", "no-cache");
  httpd_resp_set_hdr(req, "Connection", "close");

  res = httpd_resp_set_type(req, _STREAM_CONTENT_TYPE);
  if (res != ESP_OK)
    return res;

  while (stream_active)
  {
    delay(1000 / FPS_VIDEO); // FPS

    fb = esp_camera_fb_get();
    if (!fb)
    {
      Serial.println(F("Camera capture failed"));
#if DEPURACION_T
      EnviarTelnet("Camera capture failed");
#endif
      res = ESP_FAIL;
      break;
    }

    if (fb->format != PIXFORMAT_JPEG)
    {
      bool jpeg_converted = frame2jpg(fb, 80, &_jpg_buf, &_jpg_buf_len);
      esp_camera_fb_return(fb);
      fb = NULL;
      if (!jpeg_converted)
      {
        Serial.println(F("JPEG compression failed"));
#if DEPURACION_T
        EnviarTelnet("JPEG compression failed");
#endif
        res = ESP_FAIL;
        break;
      }
    }
    else
    {
      _jpg_buf_len = fb->len;
      _jpg_buf = fb->buf;
    }

    String hor = hActual();

    size_t hlen = snprintf((char *)part_buf, sizeof(part_buf), _STREAM_BOUNDARY);
    res = httpd_resp_send_chunk(req, (const char *)part_buf, hlen);

    if (res == ESP_OK)
    {
      hlen = snprintf((char *)part_buf, sizeof(part_buf), _STREAM_PART, hor.c_str(), _jpg_buf_len);
      res = httpd_resp_send_chunk(req, (const char *)part_buf, hlen);
    }

    if (res == ESP_OK)
    {
      res = httpd_resp_send_chunk(req, (const char *)_jpg_buf, _jpg_buf_len);
    }

    if (fb)
      esp_camera_fb_return(fb);
    else if (_jpg_buf)
      free(_jpg_buf);

    if (res != ESP_OK)
      break;
  }

  // IMPORTANTE: cerrar correctamente la transmisión
  client_active = false;
  httpd_resp_send_chunk(req, NULL, 0);
  return res;
}

void startCameraServer()
{
  config = HTTPD_DEFAULT_CONFIG();
  config.server_port = 80;

  httpd_uri_t stream_uri = {
      .uri = "/video",
      .method = HTTP_GET,
      .handler = stream_handler,
      .user_ctx = NULL,
  };

  Serial.print(F("\nIP de la transmision: http://"));
  Serial.println(WiFi.localIP());
  Serial.printf("Puerto de la transmision: '%d'\n", config.server_port);
  if (httpd_start(&stream_httpd, &config) == ESP_OK)
  {
    httpd_register_uri_handler(stream_httpd, &stream_uri);
  }
  else
  {
    Serial.println(F("Error al arrancar el servicio."));
  }

  httpd_uri_t index_uri = {
      .uri = "/",
      .method = HTTP_GET,
      .handler = index_handler,
      .user_ctx = NULL,
  };
  httpd_register_uri_handler(stream_httpd, &index_uri);
}

void stopCameraServer()
{
  if (stream_httpd)
  {
    stream_active = false;
    delay(200);

    // Forzar cierre
    httpd_stop(stream_httpd);
    stream_httpd = NULL;

    Serial.println(F("Servidor de cámara completamente detenido"));
  }
}
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
void loop()
{
#if WDT
  esp_task_wdt_reset();
#endif
  if (enviarFoto)
  {
    if (usrActivo || solicFot[0] || solicFot[1])
    {
      TomarFoto();
      enviarFoto = false;
    }
  }
  nuevosMsj();
#if TIEMP_MOV_F
  usrActivo ? sensorMovimientoFijo() : (void)0;
#else
  usrActivo ? sensorMovimientoAuto() : (void)0;
#endif

  if ((millis() - tAntBat) > 180000) // 3 min.
  {
    WiFiClient client;
    if (!client.connect("www.google.com", 80))
    {
      if (desc > 2 && !stream_active)
      {
        // Serial.println(F("Perdida de conexion."));
        setString("E: Perdida de conexion.\n");
        delay(1000);
        ESP.restart();
      }
      desc++;
      WiFi.reconnect();
    }
    else
    {
      client.stop();
      desc = 0;
    }
    apaAutomat();
    temperatura();
    bateria(voltaje());
    tAntBat = millis();
  }
  delay(40);
}

// -------------------------------
#if DEPURACION_T
void EnviarTelnet(String txt)
{
  TelnetStream.print(txt);
  TelnetStream.println();
}
#endif

#if RESET_NVC
void resetNVC()
{
  // LIMPIAR LA MEMORIA NVS
  nvs_flash_erase();
  nvs_flash_init();
  while (true)
    ;
}
#endif

bool invAct(int i)
{
  if (i == 0)
  {
    return true;
  }
  else
  {
    if (invitadActive)
    {
      return true;
    }
    else
    {
      return false;
    }
  }
}

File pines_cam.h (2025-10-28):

// CAMERA_MODEL_AI_THINKER
#define PWDN_GPIO_NUM 32
#define RESET_GPIO_NUM -1
#define XCLK_GPIO_NUM 0
#define SIOD_GPIO_NUM 26
#define SIOC_GPIO_NUM 27
#define Y9_GPIO_NUM 35
#define Y8_GPIO_NUM 34
#define Y7_GPIO_NUM 39
#define Y6_GPIO_NUM 36
#define Y5_GPIO_NUM 21
#define Y4_GPIO_NUM 19
#define Y3_GPIO_NUM 18
#define Y2_GPIO_NUM 5
#define VSYNC_GPIO_NUM 25
#define HREF_GPIO_NUM 23
#define PCLK_GPIO_NUM 22

const char *welcome = "📱 COMANDOS ESP32-CAM\n/alertDura : on/off alerta de duracion del movimiento.\n/apagAuto: on/off apagarse de: 19:00 - 07:00.\n/configDatos: Config. de las credenciales.\n/configOTA: Activar funcion de actualizacion mediante OTA.\n/alertBotLento: on/off de las alertas cuando la conexion con el bot esta lento.\n/iniciarVideo: Iniciar transmision de video atravez de su red local.\n/pararVideo: Detener la transmision de video en su red local.\n/estadoInv: on/off el usuario invitado.\n/reiniciar: Reiniciar la ESP32 - CAM.\n\n💡 INFORMACION DEL LED\n- Parpadeo-Rapido: Esta en modo configuracion o error de acceso a la memoria.\n- Parpadeo-Normal: Calibrando sensor al iniciar.\n- Un Parpadeo: Captura una foto.\n-Encendido: Cuando se detecta movimiento(solo si esta activado la opcion).\n\n🛜 CONFIGURAR WIFI\n Cuando no encuentra conexion al WiFi el dispositivo crea el AP con el nombre ESPCAM-BOT donde debe de ingresar esos datos.";
const char *bienv2 = "🚔 == ESPCAM EN LINEA == 🚨🚨";
